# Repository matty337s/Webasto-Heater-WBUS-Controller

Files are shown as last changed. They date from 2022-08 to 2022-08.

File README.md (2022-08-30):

# Webasto Heater WBUS Controller

Controller for webasto heater used in vehicles such as Land Rover Discovery 3. Used to turn on and off heater using ATTINY microcontroller, with inputs for USB, ignition and low-beam. Ignition and low-beam inputs can be used to control the heater using the standard vehicle remote control using programmed sequences. PCB designed for Hammond 1551HFLBK enclosure. Software coming soon. 

<p float="left">
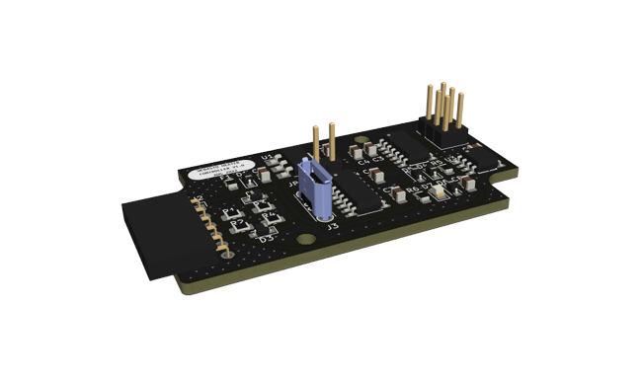
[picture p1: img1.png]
  
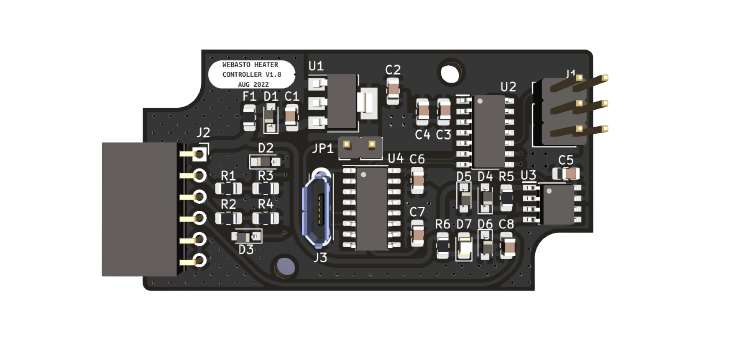
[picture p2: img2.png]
   
</p>

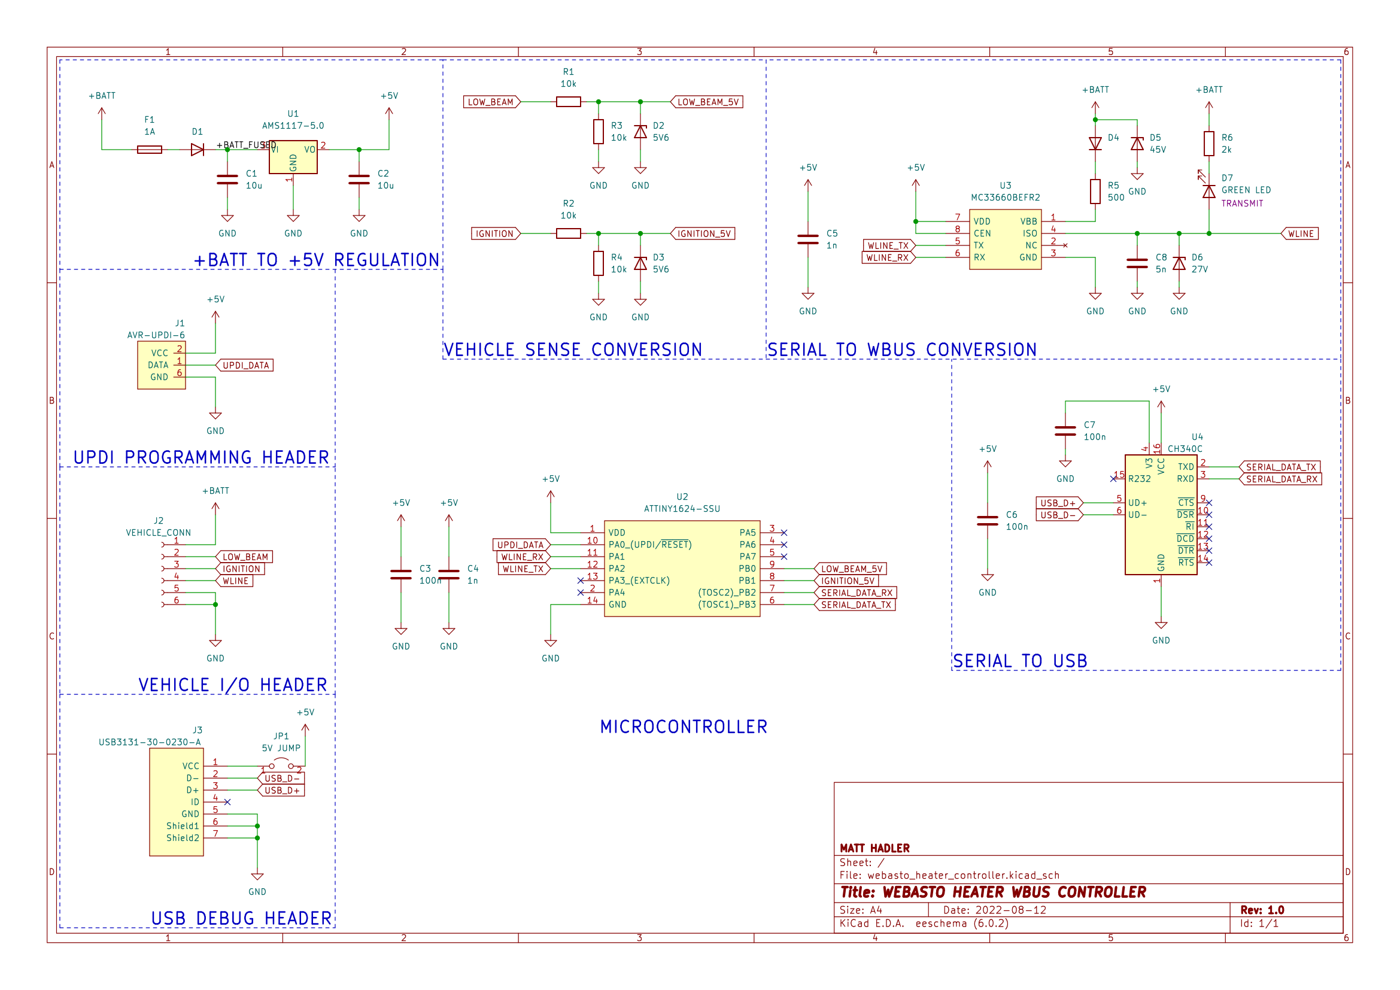
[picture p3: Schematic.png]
Schematic


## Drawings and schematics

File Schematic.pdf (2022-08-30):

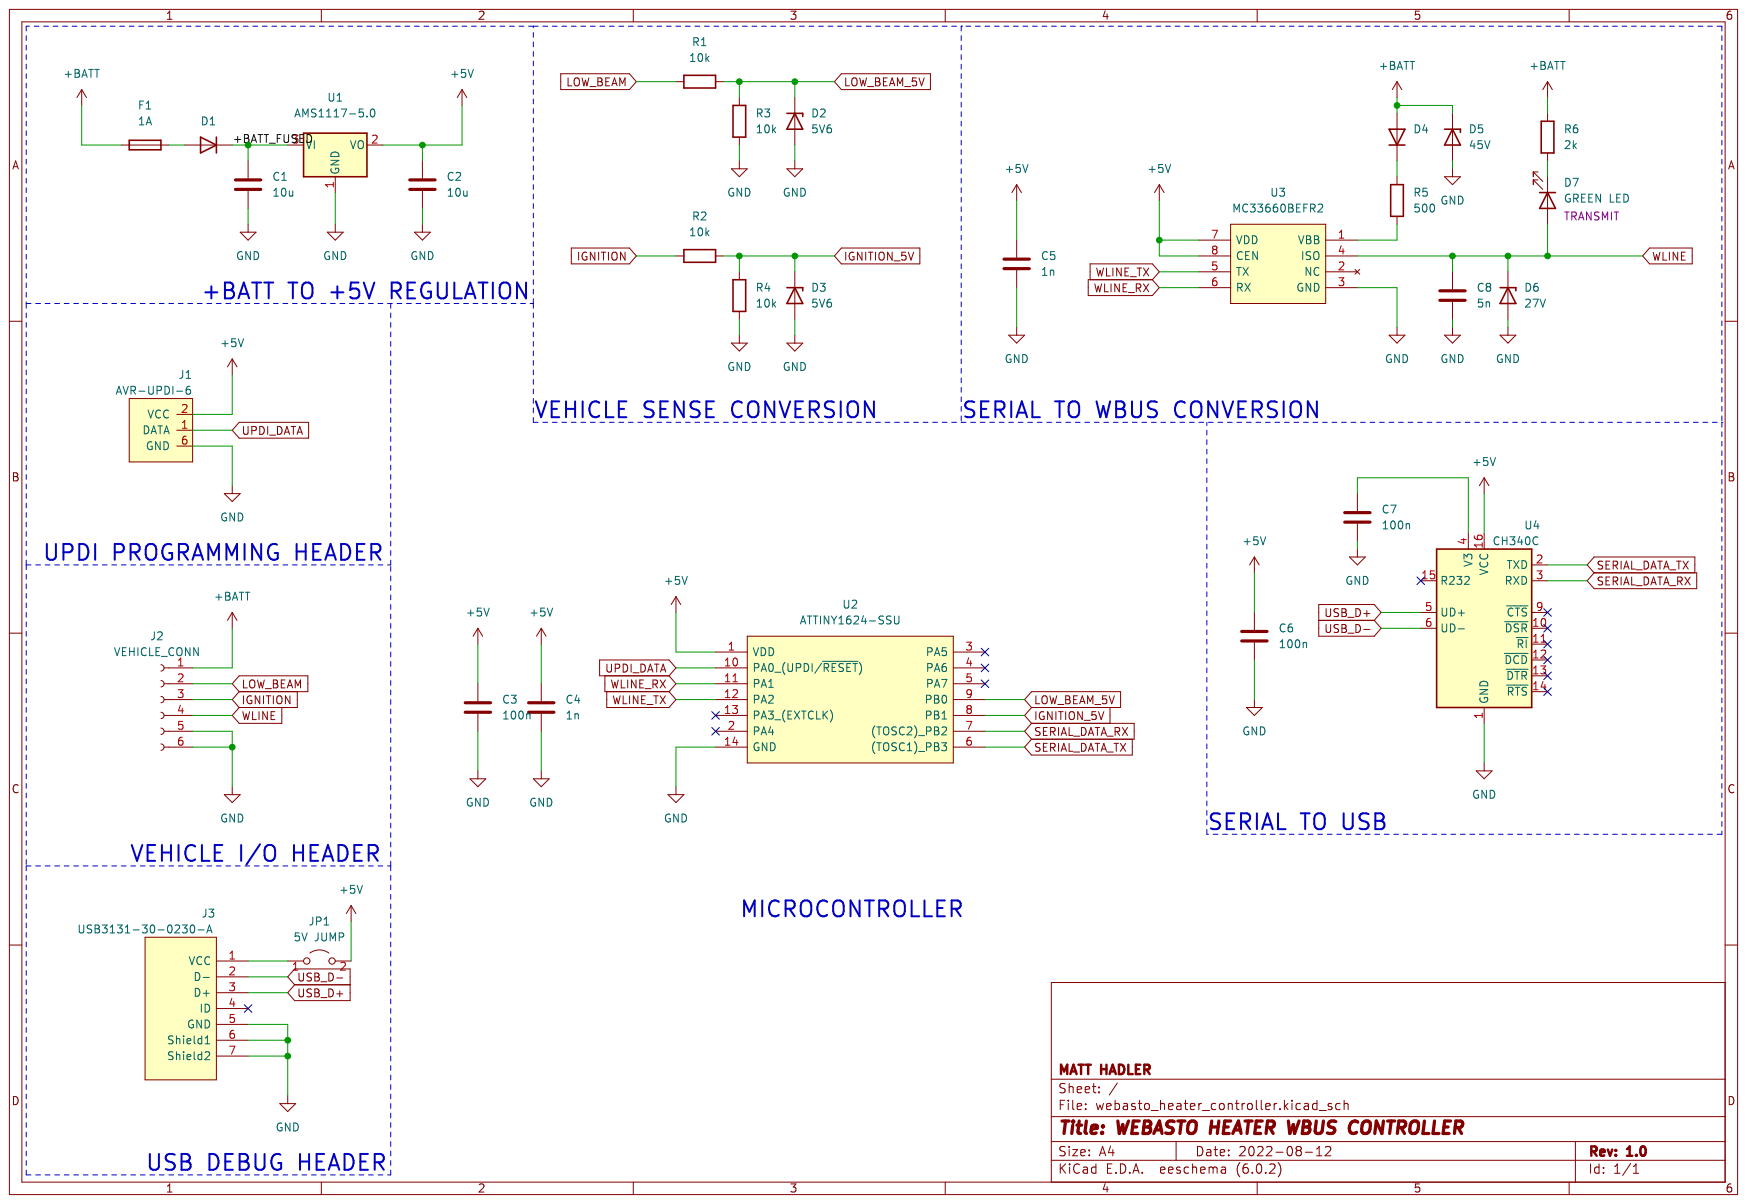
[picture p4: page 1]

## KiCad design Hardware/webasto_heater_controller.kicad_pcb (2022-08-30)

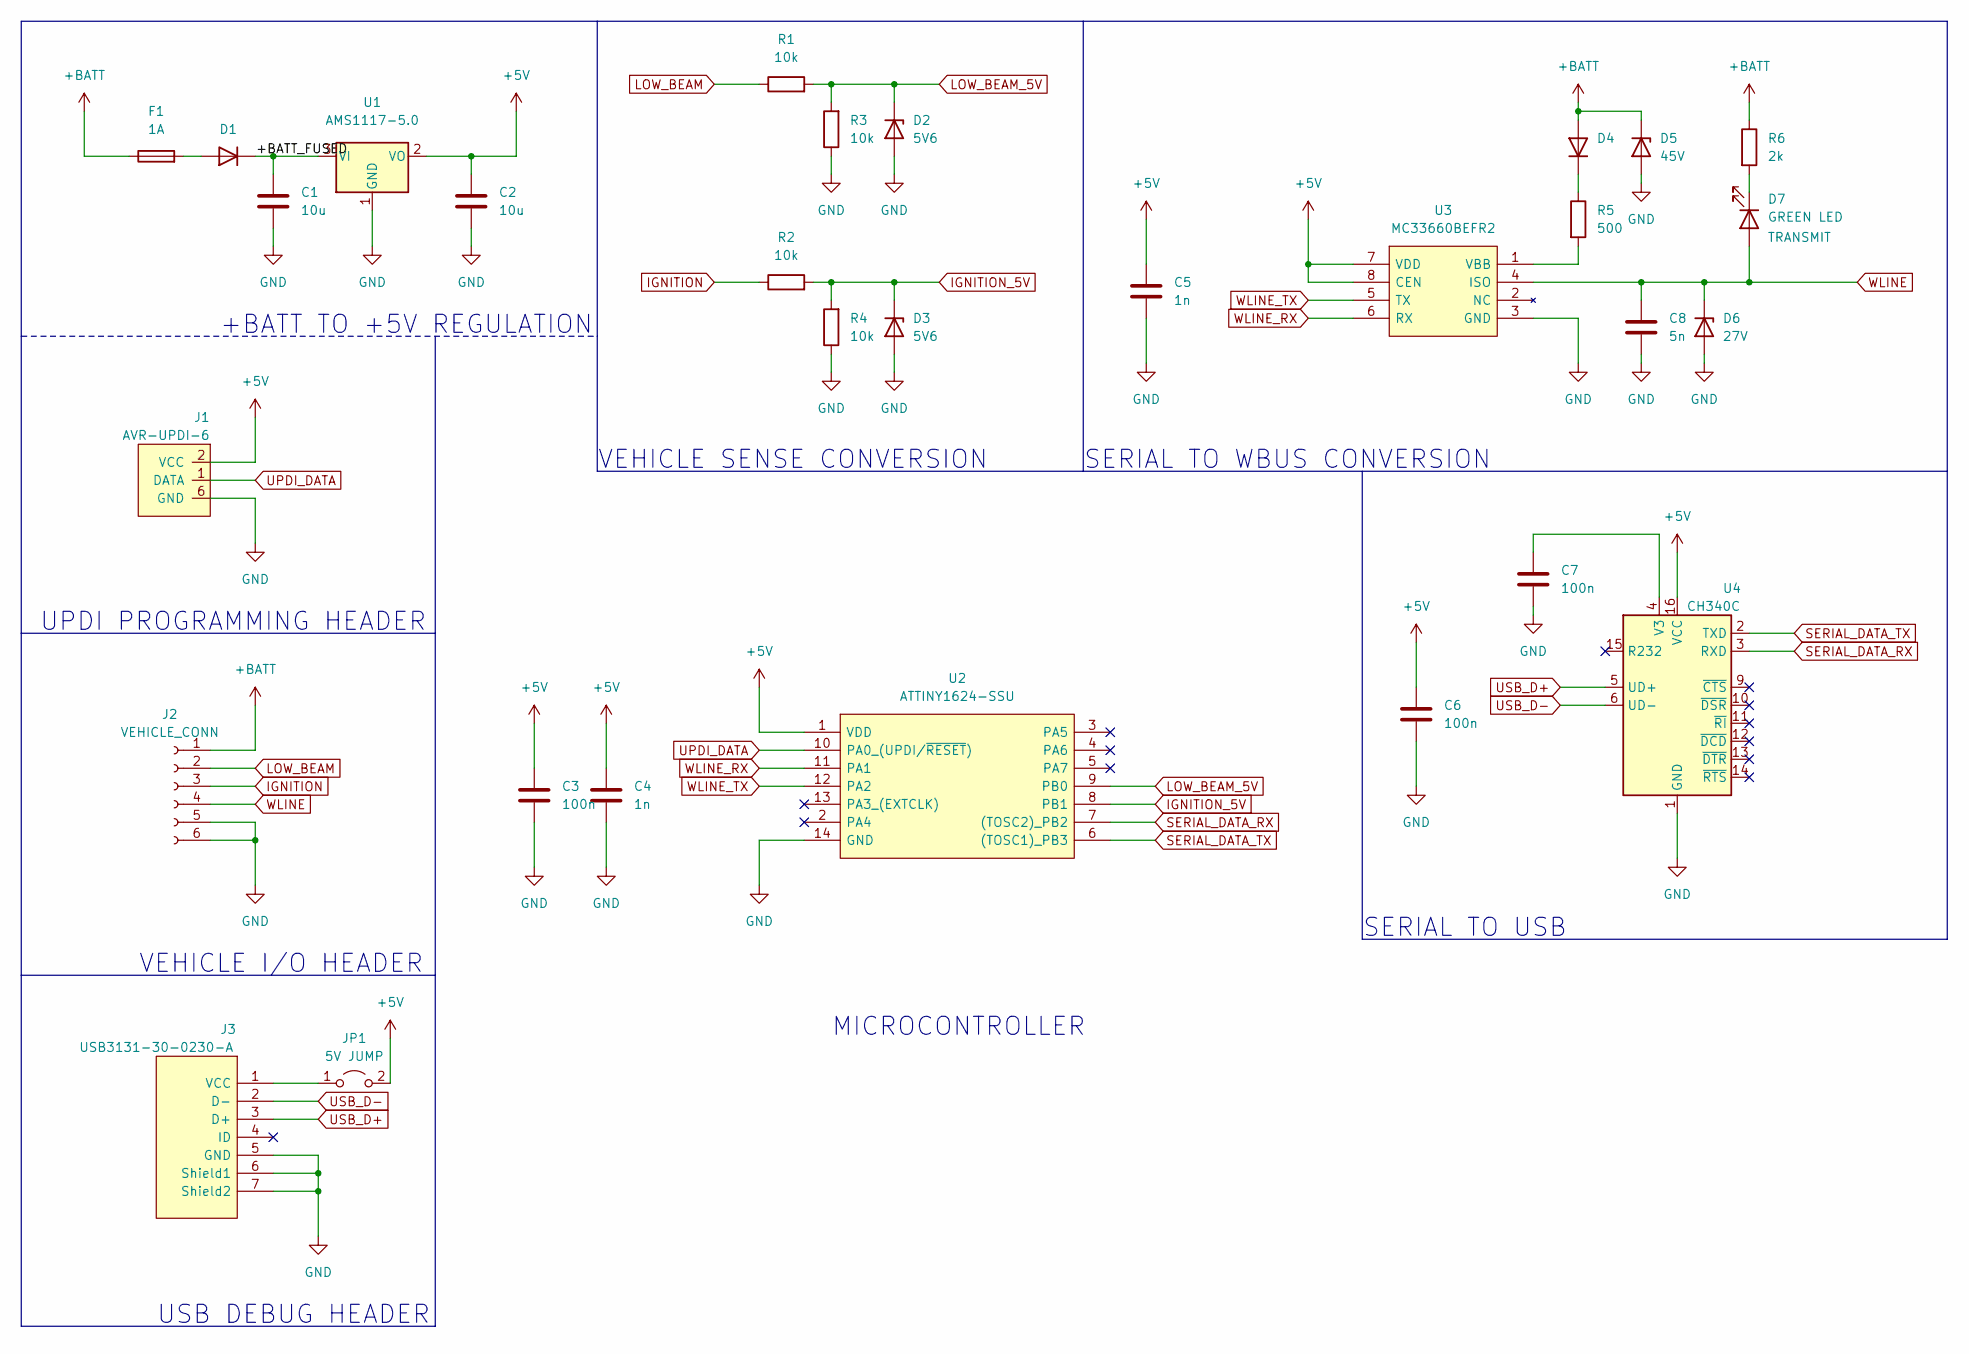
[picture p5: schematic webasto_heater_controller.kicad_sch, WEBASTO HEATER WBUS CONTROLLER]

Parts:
C1, C2: 10u; C_0805_2012Metric_Pad1.18x1.45mm_HandSolder
C3, C6, C7: 100n; C_0805_2012Metric_Pad1.18x1.45mm_HandSolder
C4, C5: 1n; C_0805_2012Metric_Pad1.18x1.45mm_HandSolder
C8: 5n; C_0805_2012Metric_Pad1.18x1.45mm_HandSolder
D1, D4: D; D_SOD-323_HandSoldering
D2, D3: 5V6; D_SOD-323_HandSoldering
D5: 45V; D_SOD-323_HandSoldering
D6: 27V; D_SOD-323_HandSoldering
D7: GREEN LED; LED_0805_2012Metric_Pad1.15x1.40mm_HandSolder
F1: 1A; Fuse_0805_2012Metric_Pad1.15x1.40mm_HandSolder
J1: AVR-UPDI-6; PinHeader_2x03_P2.54mm_Vertical
J2: VEHICLE_CONN; PinSocket_1x06_P2.54mm_Horizontal
J3: USB3131-30-0230-A; USB3131300230A; Manufacturer_Part_Number USB3131-30-0230-A; Mouser Part Number 640-USB3131300230A
JP1: 5V JUMP; PinHeader_1x02_P2.54mm_Vertical
R1, R2, R3, R4: 10k; R_0805_2012Metric_Pad1.20x1.40mm_HandSolder
R5: 500; R_0805_2012Metric_Pad1.20x1.40mm_HandSolder
R6: 2k; R_0805_2012Metric_Pad1.20x1.40mm_HandSolder
U1: AMS1117-5.0; SOT-223-3_TabPin2
U2: ATTINY1624-SSU; SOIC127P600X175-14N; Manufacturer_Part_Number ATTINY1624-SSU; Mouser Part Number 556-ATTINY1624-SSU
U3: MC33660BEFR2; SOIC127P600X175-8N; Manufacturer_Part_Number MC33660BEFR2; Mouser Part Number 841-MC33660BEFR2
U4: CH340C; SOIC-16_3.9x9.9mm_P1.27mm

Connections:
+5V: C2.1, C3.1, C4.1, C5.1, C6.1, J1.2 (VCC), JP1.2 (B), U1.2 (VO), U2.1 (VDD), U3.7 (VDD), U3.8 (CEN), U4.16 (VCC)
+BATT: D4.2 (A), D5.1 (K), F1.1, J2.1, R6.1
/+BATT_FUSED: C1.1, D1.1 (K), U1.3 (VI)
GND: C1.2, C2.2, C3.2, C4.2, C5.2, C6.2, C7.2, C8.2, D2.2 (A), D3.2 (A), D5.2 (A), D6.2 (A), J1.6 (GND), J2.5, J2.6, J3.5 (GND), J3.6 (Shield1), J3.7 (Shield2), R3.1, R4.1, U1.1 (GND), U2.14 (GND), U3.3 (GND), U4.1 (GND)
IGNITION: J2.3, R2.1
IGNITION_5V: D3.1 (K), R2.2, R4.2, U2.8 (PB1)
LOW_BEAM: J2.2, R1.1
LOW_BEAM_5V: D2.1 (K), R1.2, R3.2, U2.9 (PB0)
unnamed: C7.1, U4.4 (V3)
unnamed: D1.2 (A), F1.2
unnamed: D4.1 (K), R5.1
unnamed: D7.1 (K), R6.2
unnamed: J3.1 (VCC), JP1.1 (A)
unnamed: R5.2, U3.1 (VBB)
SERIAL_DATA_RX: U2.7 ((TOSC2)_PB2), U4.3 (RXD)
SERIAL_DATA_TX: U2.6 ((TOSC1)_PB3), U4.2 (TXD)
UPDI_DATA: J1.1 (DATA), U2.10 (PA0_(UPDI/~RESET))
USB_D+: J3.3 (D+), U4.5 (UD+)
USB_D-: J3.2 (D-), U4.6 (UD-)
WLINE: C8.1, D6.1 (K), D7.2 (A), J2.4, U3.4 (ISO)
WLINE_RX: U2.11 (PA1), U3.6 (RX)
WLINE_TX: U2.12 (PA2), U3.5 (TX)

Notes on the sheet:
UPDI PROGRAMMING HEADER
+BATT TO +5V REGULATION
SERIAL TO USB
MICROCONTROLLER
USB DEBUG HEADER
VEHICLE I/O HEADER
VEHICLE SENSE CONVERSION
SERIAL TO WBUS CONVERSION

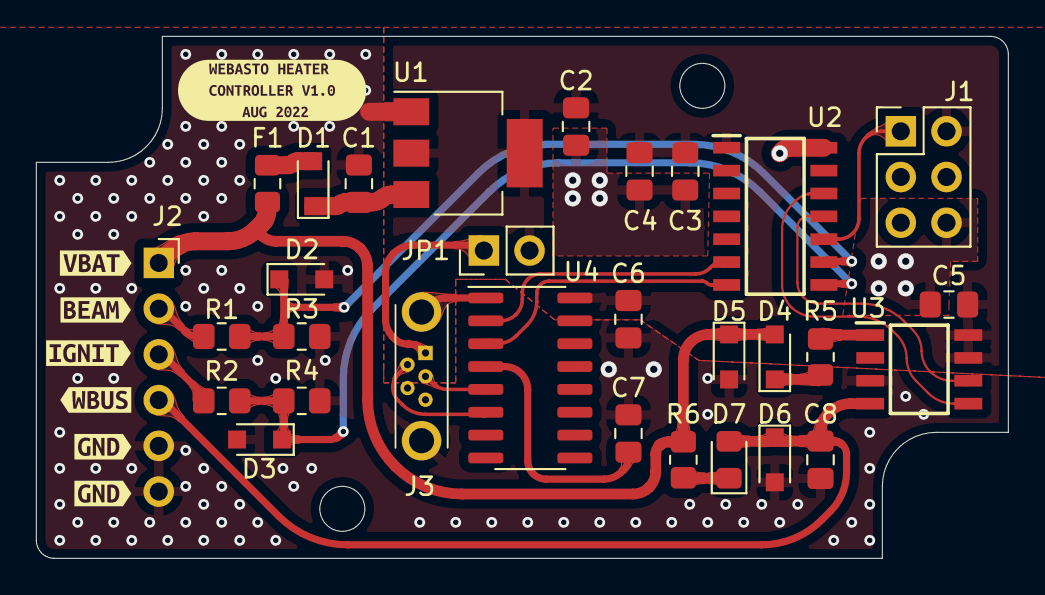
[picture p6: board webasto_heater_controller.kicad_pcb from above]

Board: 2 copper layers, 54.0 x 29.0 mm, 37 parts (0 on the bottom side), 22 nets.

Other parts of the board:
kibuzzard-62F61DC3: G***; kibuzzard-62F61DC3
kibuzzard-62F61EBF: G***; kibuzzard-62F61EBF
kibuzzard-62F61ED5: G***; kibuzzard-62F61ED5
kibuzzard-62F61EF6: G***; kibuzzard-62F61EF6
kibuzzard-62F61EFB: G***; kibuzzard-62F61EFB
kibuzzard-62F61F6C: G***; kibuzzard-62F61F6C
kibuzzard-62F62203: G***; kibuzzard-62F62203

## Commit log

2022-08-30 Added Images
    [Disco3_FBH-CuBottom.gbr, Disco3_FBH-CuTop.gbr, Disco3_FBH-EdgeCuts.gbr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]
2022-08-30 Added Schematic
